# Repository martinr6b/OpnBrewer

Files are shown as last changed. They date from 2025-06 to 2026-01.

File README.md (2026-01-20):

# 🍵OpnBrewer


<br></br>
## Work in progress
## ABOUT
This project was only started because i was bored, and it's a good way for me to gain some experience. This is so far only being made 100% compatible with the EDG355.B1 model of Nescafe dolce gusto machines
<br></br>
## FEATURES
- rgb led indicator
- home assistant integration using [ESPHOME](https://esphome.io 'esphome main page')
- auto power off
- fully customizable
- thermosat integration for adjustable target temp
- all safety features implemented (when final version)
<br></br>
## Compatibility
- So far only verified working with the **Nescafe dolce gusto EDG355.B1**
- I intend do make it compatible with many more models in the future
<br></br>
## HOW-TO
- TODO (lol)
<br></br>
## PROGRESS
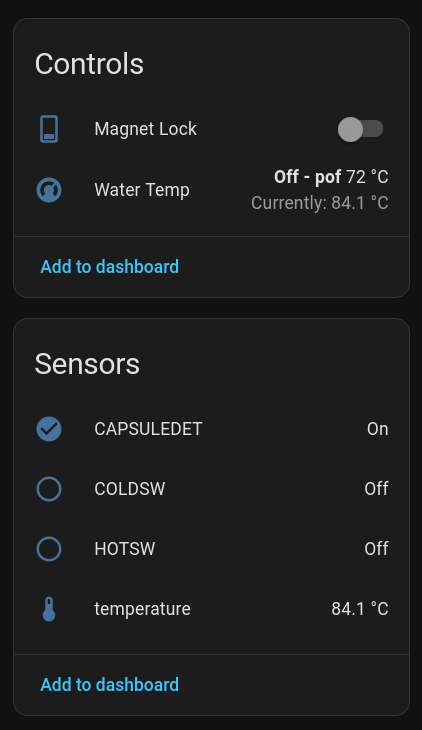
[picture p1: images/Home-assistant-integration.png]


This is the way the Coffee machine is currently exposed to Home Assistant
<br></br>
## TODO 
- Fix delayed temperature readings
- Order Power Supply PCB
- Finish Top PCB

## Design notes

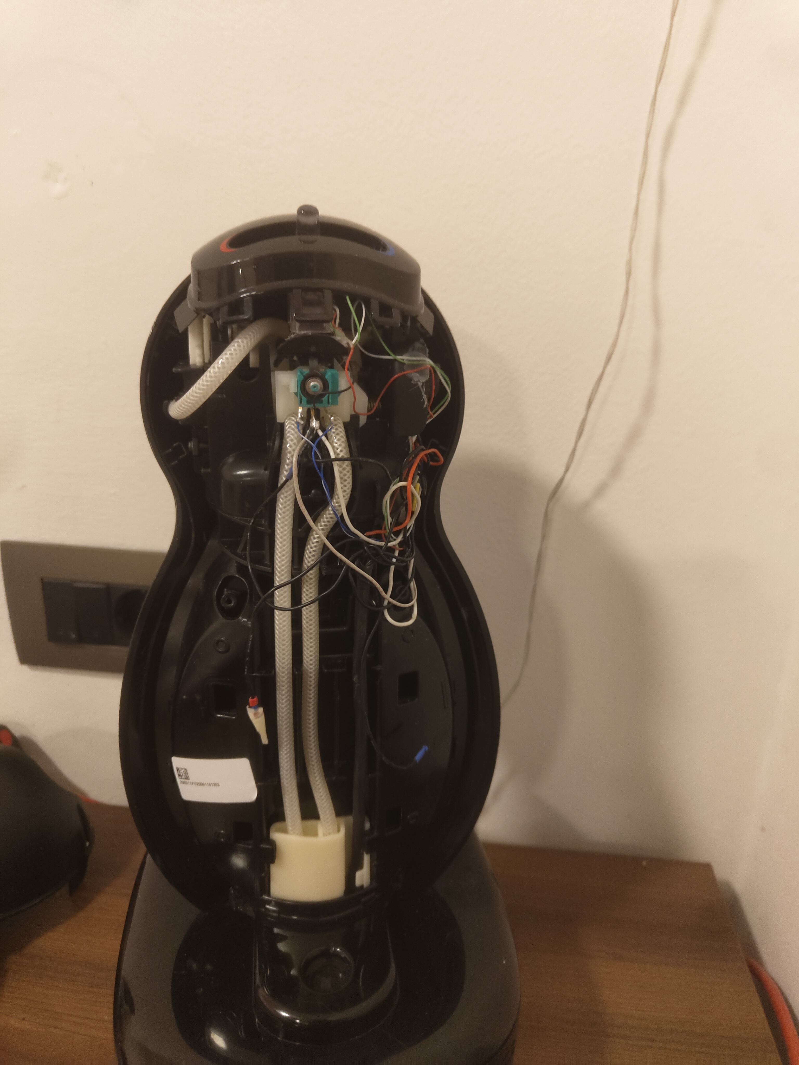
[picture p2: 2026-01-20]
images/openrear1.jpg

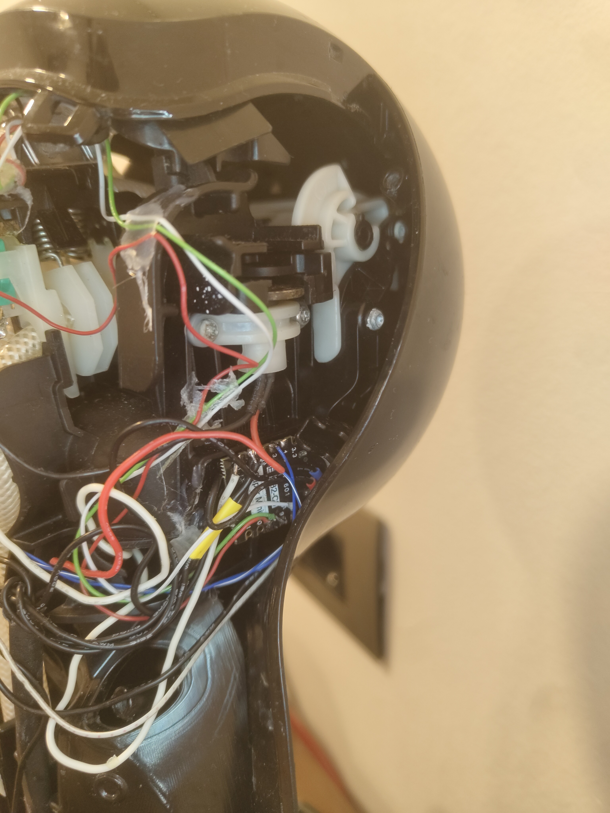
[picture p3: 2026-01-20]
images/openrear3.jpg

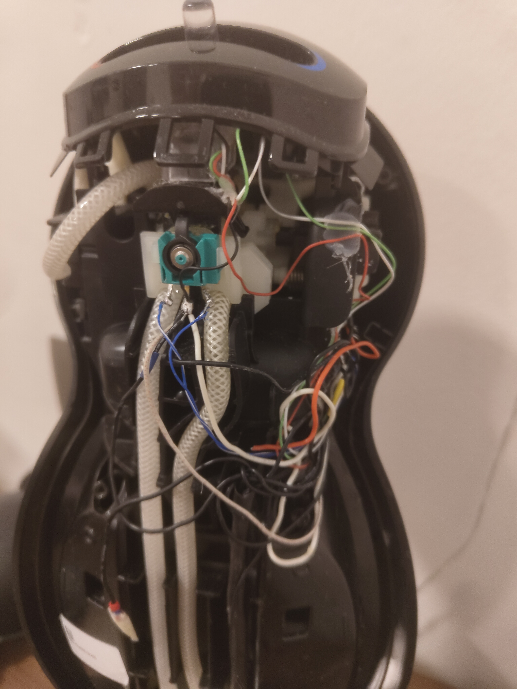
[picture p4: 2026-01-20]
images/openrear2.jpg

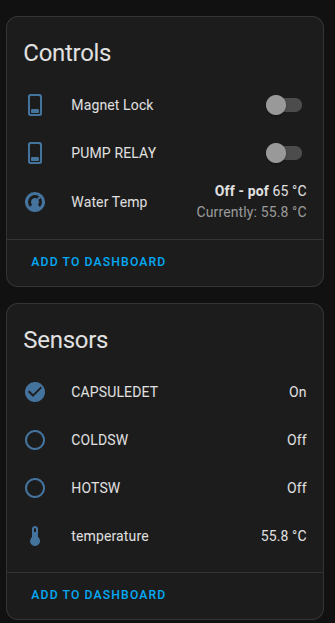
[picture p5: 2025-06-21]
images/HA exposes.png

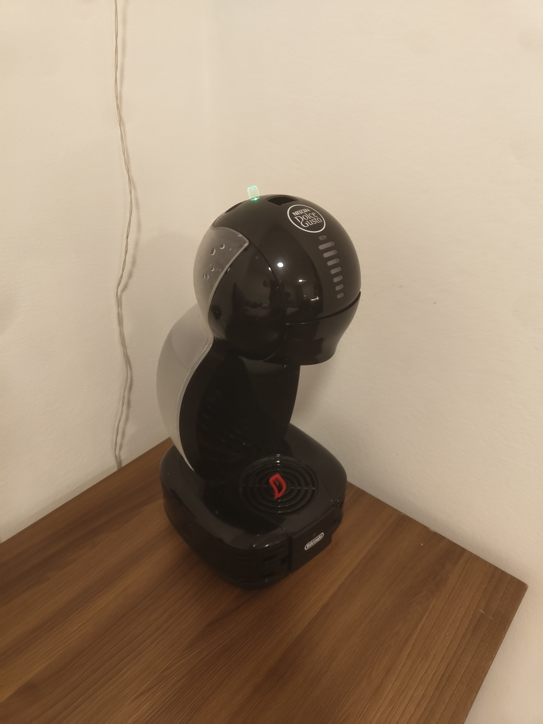
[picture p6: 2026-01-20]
images/side_closed.jpg

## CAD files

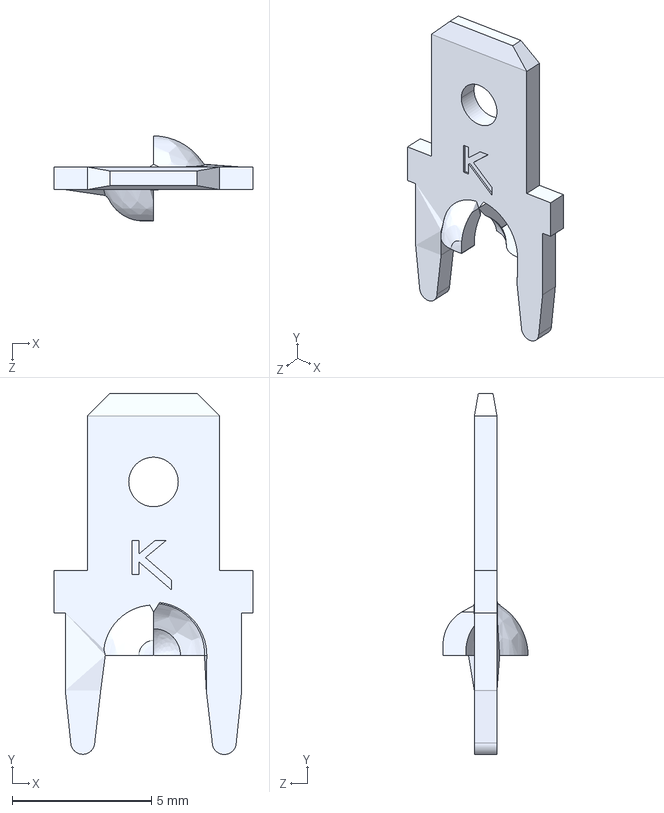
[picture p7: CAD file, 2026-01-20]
PCBs/Power supply board/KiCad Project files/Component libraries/1212-ST/1212-ST.step
7.14 x 13.0 x 3.06 mm

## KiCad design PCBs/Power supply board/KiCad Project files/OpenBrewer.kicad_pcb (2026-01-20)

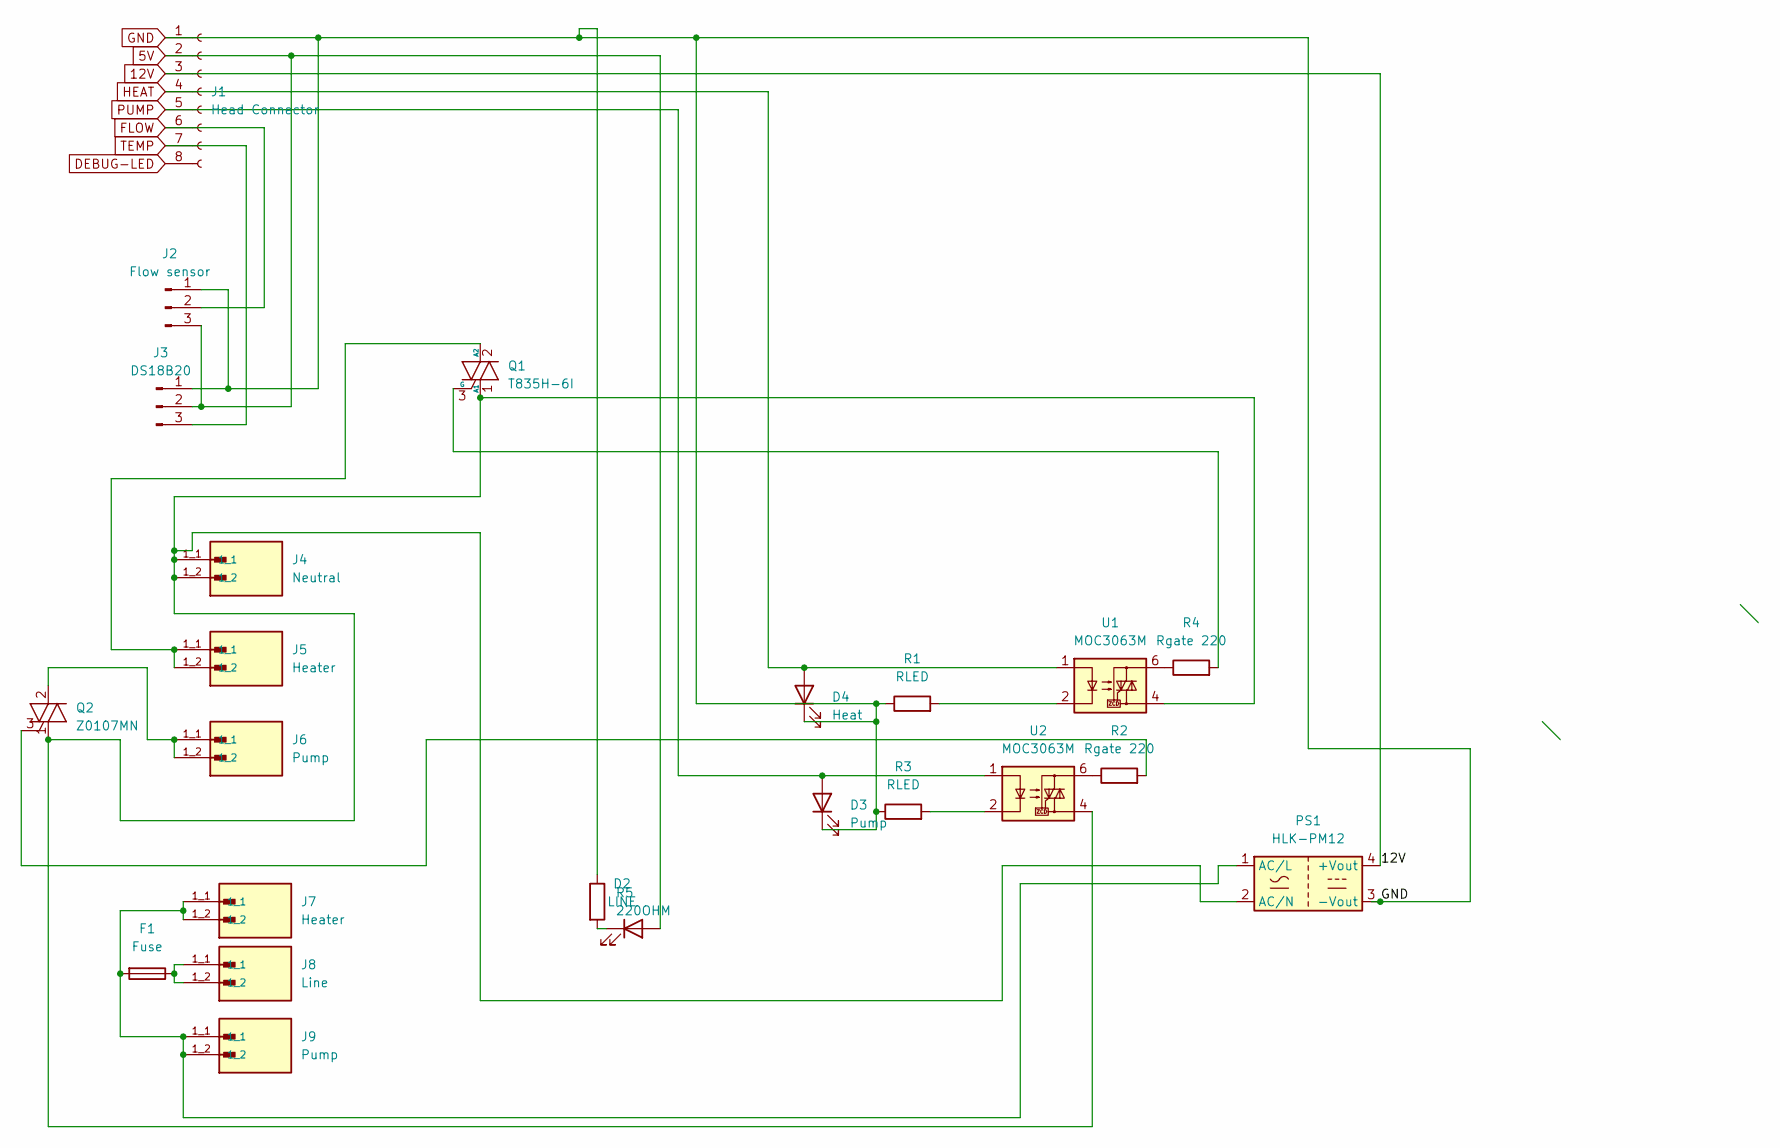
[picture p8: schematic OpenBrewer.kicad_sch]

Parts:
D2: LINE; LED_D3.0mm
D3: Pump; LED_D3.0mm
D4: Heat; LED_D3.0mm
F1: Fuse; Fuseholder_Cylinder-5x20mm_Schurter_0031_8201_Horizontal_Op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
J1: Head Connector; JST_PH_B8B-PH-K_1x08_P2.00mm_Vertical
J2: Flow sensor; JST_PH_B3B-PH-K_1x03_P2.00mm_Vertical
J3: DS18B20; JST_PH_B3B-PH-K_1x03_P2.00mm_Vertical
J4: Neutral; KEYSTONE_1212-ST; PARTREV C
J5, J7: Heater; KEYSTONE_1212-ST; PARTREV C
J6, J9: Pump; KEYSTONE_1212-ST; PARTREV C
J8: Line; KEYSTONE_1212-ST; PARTREV C
PS1: HLK-PM12; Converter_ACDC_Hi-Link_HLK-PMxx
Q1: T835H-6I; TO-220-3_Vertical
Q2: Z0107MN; SOT-223
R1, R3: RLED; R_1206_3216Metric_Pad1.30x1.75mm_HandSolder
R2, R4: Rgate 220; R_0201_0603Metric_Pad0.64x0.40mm_HandSolder
R5: 220OHM; R_0603_1608Metric_Pad0.98x0.95mm_HandSolder
U1, U2: MOC3063M; DIP-6_W10.16mm_LongPads

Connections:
5V: D2.2 (A), J1.2, J2.3, J3.2
12V: J1.3, PS1.4 (+Vout)
DEBUG-LED: J1.8
FLOW: J1.6, J2.2
GND: D3.1 (K), D4.1 (K), J1.1, J2.1, J3.1, PS1.3 (-Vout), R1.1, R3.1, R5.1
HEAT: D4.2 (A), J1.4, U1.1
unnamed: D2.1 (K), R5.2
unnamed: F1.1, J8.1_1, J8.1_2
unnamed: F1.2, J7.1_1, J7.1_2, J9.1_1, J9.1_2, PS1.1 (AC/L)
unnamed: J4.1_1, J4.1_2, PS1.2 (AC/N), Q1.1 (A1), Q2.1 (A1), U1.4, U2.4
unnamed: J5.1_1, J5.1_2, Q1.2 (A2)
unnamed: Q1.3 (G), R4.2
unnamed: J6.1_1, J6.1_2, Q2.2 (A2), Q2.4 (A4)
unnamed: Q2.3 (G), R2.2
unnamed: R1.2, U1.2
unnamed: R2.1, U2.6
unnamed: R3.2, U2.2
unnamed: R4.1, U1.6
PUMP: D3.2 (A), J1.5, U2.1
TEMP: J1.7, J3.3

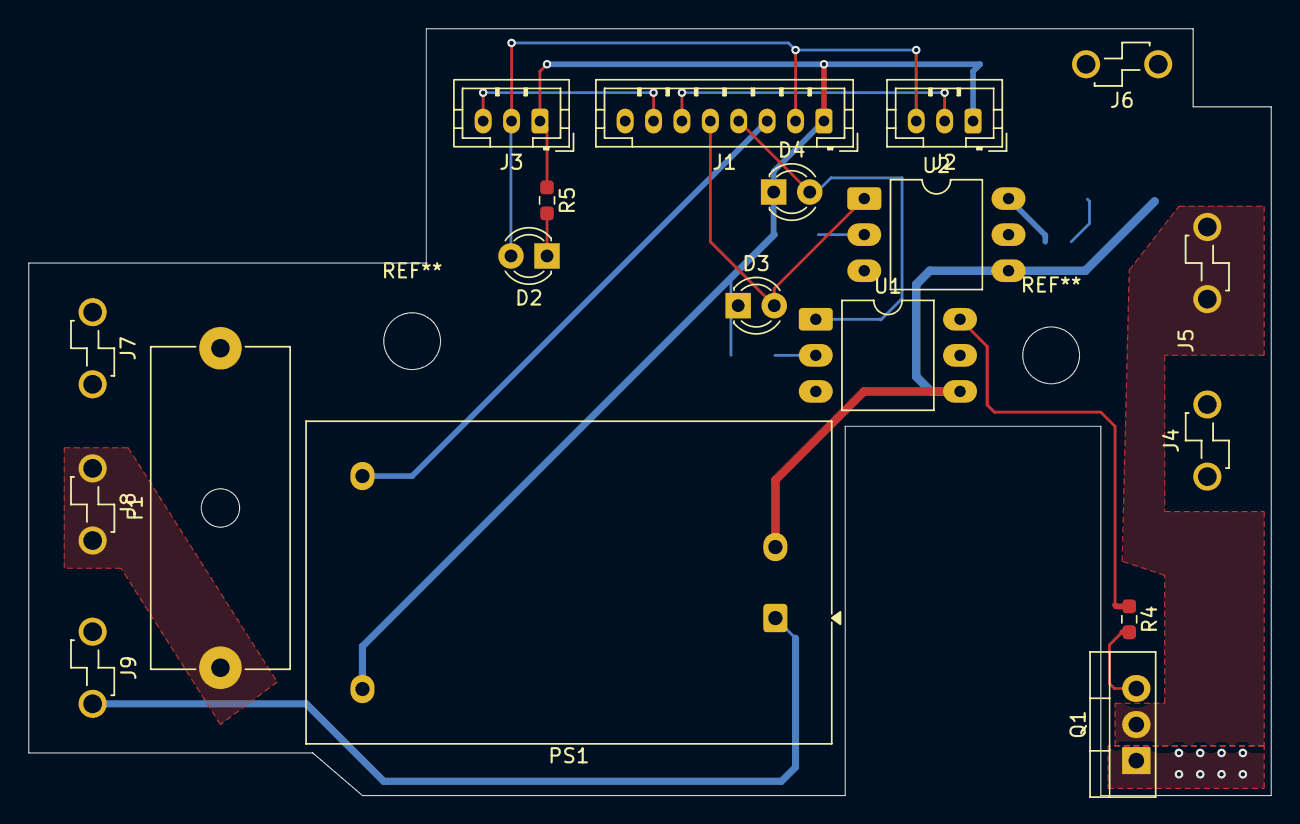
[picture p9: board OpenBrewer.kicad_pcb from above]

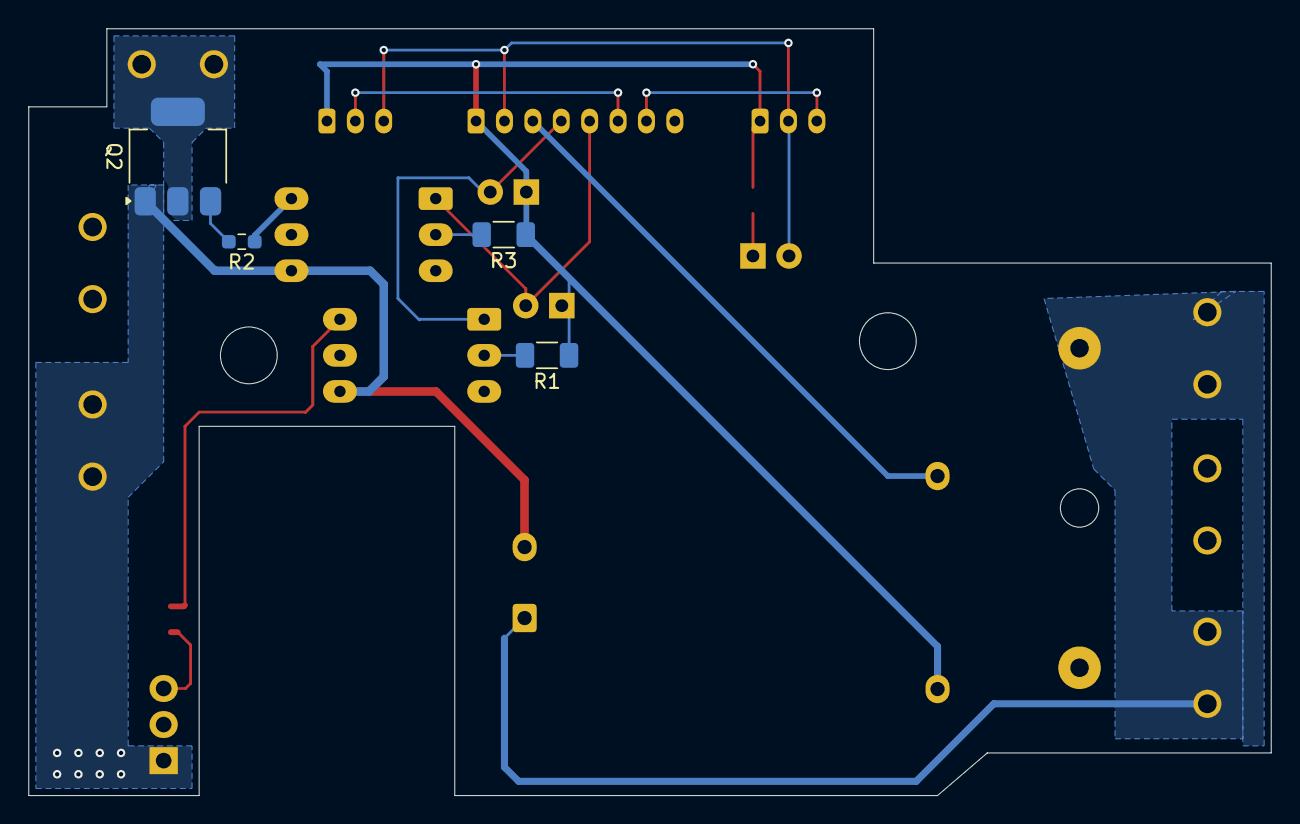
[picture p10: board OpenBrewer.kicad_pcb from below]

Board: 2 copper layers, 87.5 x 54.0 mm, 23 parts (4 on the bottom side), 19 nets.

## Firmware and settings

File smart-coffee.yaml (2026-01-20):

esphome:
  name: smart-coffee
  friendly_name: Smart Coffee
esp32:
  board: esp32-c3-devkitm-1 
  framework:
    type: arduino
logger:
ota:
  - platform: esphome
api:
  encryption:
    key: "HA-ENCRYPTION-KEY"
wifi:
  ssid: !secret wifi_ssid
  password: !secret wifi_password
  ap:
    ssid: "Smart-Coffee Fallback Hotspot"
    password: "12345678"
captive_portal:
#SETUP END

one_wire:
  - platform: gpio
    pin: GPIO1
sensor:
  - platform: dallas_temp
    name: temperature
    id: temperature
    update_interval: 1s


# hot switch
binary_sensor:
  - platform: gpio
    pin:
      number: GPIO2
      inverted: True
      mode: 
        pullup: True
        input: True
    name: HOTSW
    on_release: 
      then:
        - switch.turn_off: PUMP
        - light.turn_off: rgbled_state

        - climate.control: 
            mode: HEAT
            target_temperature: 72
            id: thermostat1
        

    on_press: 
      then:
      
        - switch.turn_on: PUMP
        - light.turn_on: 
            id: rgbled_state
            red: 80%
            green: 20%
            blue: 0%

        - climate.control: 
            mode: HEAT
            target_temperature: 96
            id: thermostat1
        


            
        

# cold switch 
  - platform: gpio
    pin:
      number: GPIO3
      inverted: True
      mode: 
        pullup: True
        input: True
    name: COLDSW
    on_release: 
      then:
        - switch.turn_off: PUMP
        - light.turn_off: rgbled_state

    on_press: 
      then:
        - switch.turn_on: PUMP
        - light.turn_on: 
            id: rgbled_state
            red: 0%
            green: 20%
            blue: 65%
            
#capsule detection
  - platform: gpio
    name: CAPSULEDET
    pin:
      number: GPIO0
      inverted: True
      mode: 
        pullup: True
        input: True
# pump heater and magnetic lock
switch:
  - platform: gpio
    pin: GPIO7
    id: HEAT
    restore_mode: ALWAYS_OFF
    on_turn_on: 
      then:
        - light.control: 
            id: rgbled_state
            red: 50%
            green: 50%
            blue: 25%
            effect: fast pulse
  - platform: gpio
    pin: GPIO5
    id: PUMP
    restore_mode: ALWAYS_OFF
  - platform: gpio
    pin:
      number: GPIO4
      inverted: True

    name: Magnet Lock
    id: LOCK
    restore_mode: ALWAYS_OFF
# rgb led 
output:
  - platform: ledc
    id: red
    pin: GPIO10
  - platform: ledc
    id: green
    pin: GPIO9
  - platform: ledc
    id: blue
    pin: GPIO8
light:
  - platform: rgb
    blue: blue
    red: red
    green: green
    id: rgbled_state
    effects:
      - pulse:
      - pulse:
          name: "Fast Pulse"
          transition_length: 0.5s
          update_interval: 0.5s
          min_brightness: 0%
          max_brightness: 100%
      - pulse:
          name: "Slow Pulse"
          transition_length: 2s
          update_interval: 1s

#thermostat
  
climate:
  - platform: thermostat
    name: "Water Temp"
    id: thermostat1
    sensor: temperature
    min_heating_off_time: 1s
    min_heating_run_time: 1s
    on_boot_restore_from: default_preset
    min_idle_time: 1s
    heat_action:
      - switch.turn_on: HEAT
    idle_action:
      - switch.turn_off: HEAT
    default_preset: pof
    visual: 
      max_temperature: 95
      min_temperature: 0   
    preset:
      - name: pof
        default_target_temperature_low: 20 °C
    on_state:
      then:
      # auto power off
      - if:
          condition:
            and:
              - for:
                  time: 5min
                  condition:
                    lambda: return id(thermostat1).mode == climate::CLIMATE_MODE_HEAT;
              - lambda: return id(thermostat1).mode == climate::CLIMATE_MODE_HEAT;
          then:
            - climate.control:
                id: thermostat1
                mode: "OFF"
            - logger.log: "Turned off heating after 5 minutes of continuous operation"
            - light.turn_off: rgbled_state
      - if:
        # heated indicator
            condition:
              lambda: return id(thermostat1).current_temperature > 85;
            then:
              - light.turn_on:
                  id: rgbled_state
                  red: 10%  # Orange
                  green: 50%
                  blue: 10%
                  effect: Slow Pulse
            

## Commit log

2026-01-20 Refactor smart-coffee.yaml configuration
    Updated encryption key, modified RGB light colors, and adjusted climate control settings for hot and cold switches.
2026-01-20 Added board designs
    [1212-ST.step, OpenBrewer.kicad_pcb, OpenBrewer.kicad_sch]
2026-01-20 added gerbers
    [OpenBrewer-B_Cu.gbr, OpenBrewer-B_Mask.gbr, OpenBrewer-B_Paste.gbr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]
